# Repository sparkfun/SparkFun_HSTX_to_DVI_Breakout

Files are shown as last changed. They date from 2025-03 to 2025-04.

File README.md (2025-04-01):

SparkFun HSTX to DVI Breakout
========================================

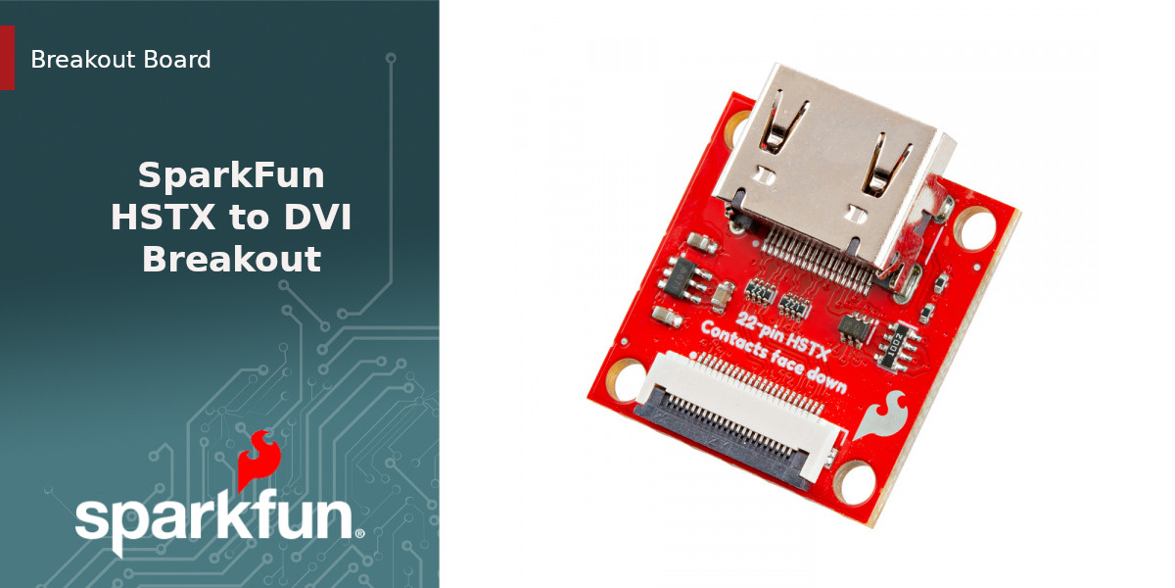
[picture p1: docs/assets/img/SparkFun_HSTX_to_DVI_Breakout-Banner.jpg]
SparkFun HSTX to DVI Breakout (https://www.sparkfun.com/sparkfun-hstx-to-dvi-breakout.html)


[*SparkFun HSTX to DVI Breakout  (BOB-28468)*](https://www.sparkfun.com/sparkfun-hstx-to-dvi-breakout.html)

The SparkFun HSTX to DVI Breakout takes the 22-pin interface found on the HSTX connector on the IoT RedBoard - RP2350 as well as the camera and display connectors on a Rasbperry Pi 5 and translates it to an HDMI connector for DVI output.

The board includes a 22-pin flex cable connector and HDMI connector along with the required components to level shift and boost the voltage for compatability with DVI signal requirements.

Repository Contents
-------------------

* **/Hardware** - Eagle design files (.brd, .sch)

Product Versions
----------------
* [BOB-28468](https://www.sparkfun.com/sparkfun-hstx-to-dvi-breakout.html) - HSTX to DVI Breakout for the RedBoard IoT - RP2350.

License Information
-------------------

This product is _**open source**_! 

Please review the LICENSE.md file for license information. 

If you have any questions or concerns on licensing, please contact technical support on our [SparkFun forums](https://forum.sparkfun.com/viewforum.php?f=152).

Distributed as-is; no warranty is given.

- Your friends at SparkFun.

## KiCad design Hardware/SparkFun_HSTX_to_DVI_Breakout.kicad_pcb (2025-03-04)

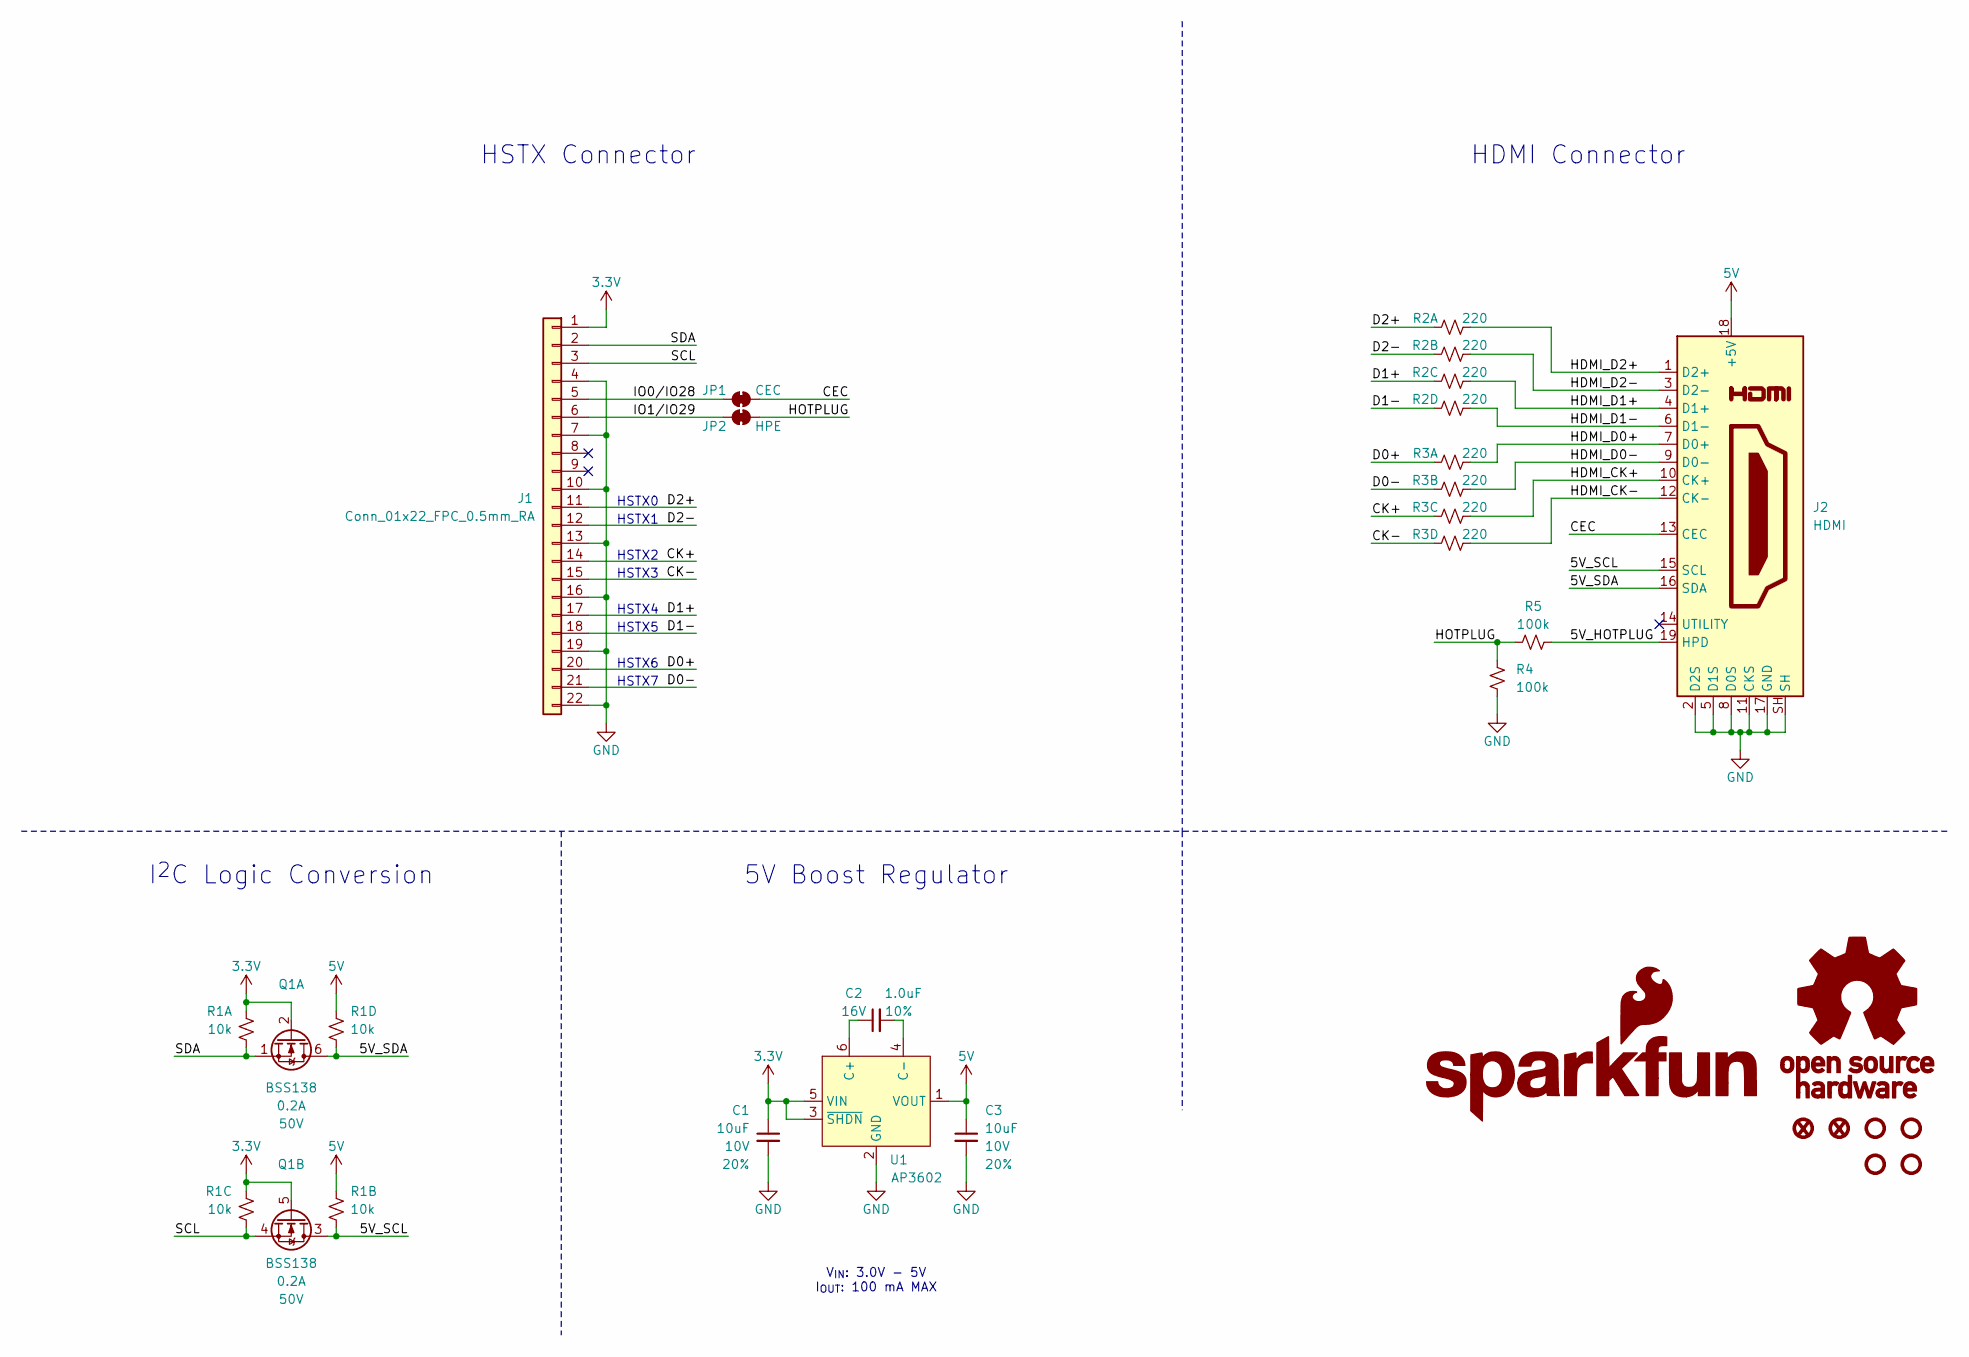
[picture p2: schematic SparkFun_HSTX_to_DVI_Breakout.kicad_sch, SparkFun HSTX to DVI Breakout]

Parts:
C1, C3: 10uF; C_0603_1608Metric; Voltage 10V; Tolerance 20%
C2: 1.0uF; C_0603_1608Metric; Voltage 16V; Tolerance 10%
FID1, FID2: Fiducial_0.5mm; Fiducial_0.5mm_Mask1mm
G1: SparkFun_Logo
G2: OSHW_Logo; Creative_Commons_License
J1: Conn_01x22_FPC_0.5mm_RA; FPC_0.5mm-22_RA
J2: HDMI; HDMI_A_19P_SMD
JP1: CEC; Jumper_2_NC_Trace
JP2: HPE; Jumper_2_NC_Trace
Q1: BSS138; SOT-363
R1: 10k; R_1206_Array_Convex
R2, R3: 220; R_0804_Array_Convex
R4, R5: 100k; R_0402_1005Metric
ST1, ST2, ST3, ST4: Standoff
U1: AP3602; SOT23-6

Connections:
3.3V: C1.1, J1.1, Q1.2 (G), Q1.5 (G), R1.2, R1.6, U1.3 (~SHDN), U1.5 (VIN)
5V: C3.1, J2.18 (+5V), R1.4, R1.8, U1.1 (VOUT)
/5V_HOTPLUG: J2.19 (HPD), R5.2
/5V_SCL: J2.15 (SCL), Q1.3 (D), R1.3
/5V_SDA: J2.16 (SDA), Q1.6 (D), R1.7
/CEC: J2.13 (CEC), JP1.2 (B)
/CK+: J1.14, R3.5
/CK-: J1.15, R3.7
/D0+: J1.20, R3.1
/D0-: J1.21, R3.3
/D1+: J1.17, R2.5
/D1-: J1.18, R2.7
/D2+: J1.11, R2.1
/D2-: J1.12, R2.3
/HDMI_CK+: J2.10 (CK+), R3.6
/HDMI_CK-: J2.12 (CK-), R3.8
/HDMI_D0+: J2.7 (D0+), R3.2
/HDMI_D0-: J2.9 (D0-), R3.4
/HDMI_D1+: J2.4 (D1+), R2.6
/HDMI_D1-: J2.6 (D1-), R2.8
/HDMI_D2+: J2.1 (D2+), R2.2
/HDMI_D2-: J2.3 (D2-), R2.4
/HOTPLUG: JP2.2 (B), R4.1, R5.1
/IO0/IO28: J1.5, JP1.1 (A)
/IO1/IO29: J1.6, JP2.1 (A)
/SCL: J1.3, Q1.4 (S), R1.5
/SDA: J1.2, Q1.1 (S), R1.1
GND: C1.2, C3.2, J1.4, J1.7, J1.10, J1.13, J1.16, J1.19, J1.22, J2.2 (D2S), J2.5 (D1S), J2.8 (D0S), J2.11 (CKS), J2.17 (GND), J2.SH, R4.2, U1.2 (GND)
unnamed: C2.1, U1.6 (C+)
unnamed: C2.2, U1.4 (C-)

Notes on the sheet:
5V Boost Regulator
HDMI Connector
HSTX3
HSTX0
HSTX5
HSTX Connector
HSTX2
HSTX4
I^{2}C Logic Conversion
V_{IN}: 3.0V - 5V I_{OUT}: 100 mA MAX
HSTX7
HSTX6
HSTX1

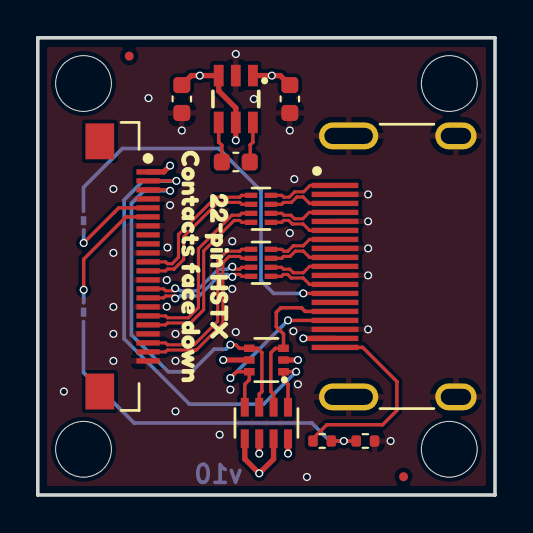
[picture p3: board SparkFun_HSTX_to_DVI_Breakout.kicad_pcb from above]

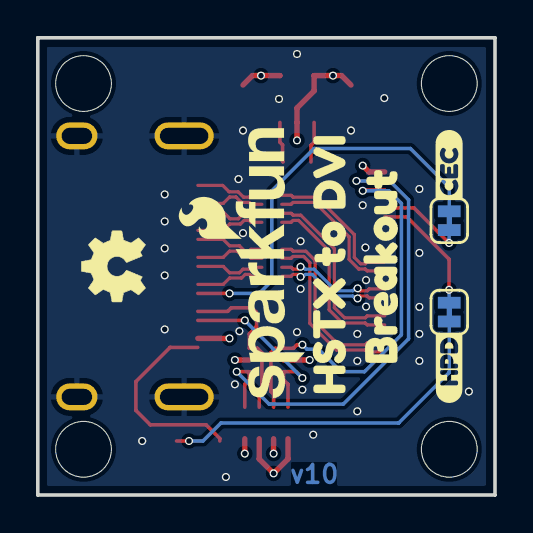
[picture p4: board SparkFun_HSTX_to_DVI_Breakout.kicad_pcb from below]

Board: 4 copper layers, 25.4 x 25.4 mm, 28 parts (7 on the bottom side), 30 nets.

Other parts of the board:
Ref**: Val**; OSHW_Logo_4mm
kibuzzard-67C21FDF: G***; kibuzzard-67C21FDF
kibuzzard-67C220EB: G***; kibuzzard-67C220EB
kibuzzard-67C223E4: G***; kibuzzard-67C223E4
kibuzzard-67C2232E: G***; kibuzzard-67C2232E
kibuzzard-67C22006: G***; kibuzzard-67C22006
kibuzzard-67C22392: G***; kibuzzard-67C22392

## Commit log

2025-03-03 Add design files for review
    [SparkFun_HSTX_to_DVI_Breakout.kicad_pcb, SparkFun_HSTX_to_DVI_Breakout.kicad_sch]
2025-03-03 Update SparkFun_HSTX_to_DVI_Breakout.kicad_pcb
    Add Impedance control to Ordering instructions
    [SparkFun_HSTX_to_DVI_Breakout.kicad_pcb]
2025-03-03 Add dates
    [SparkFun_HSTX_to_DVI_Breakout.kicad_pcb, SparkFun_HSTX_to_DVI_Breakout.kicad_sch]
2025-03-03 Update prod_id
    [SparkFun_HSTX_to_DVI_Breakout.kicad_pcb, SparkFun_HSTX_to_DVI_Breakout.kicad_sch]
2025-03-04 Design review updates
    Fix wandering measure.
    Move 5V trace to avoid splitting 3.3V vias.
    Add more ground vias.
    Delete unused README.
    [SparkFun_HSTX_to_DVI_Breakout.kicad_pcb]

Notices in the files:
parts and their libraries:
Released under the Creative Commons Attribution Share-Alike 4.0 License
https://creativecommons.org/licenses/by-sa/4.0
